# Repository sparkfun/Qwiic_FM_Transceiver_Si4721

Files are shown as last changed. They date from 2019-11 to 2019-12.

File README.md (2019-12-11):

# Qwiic FM Transceiver - Si4721

Qwiic FM Transceiver

[*Qwiic FM Transceiver - Si4721 (SPX-15853)*](https://www.sparkfun.com/products/15853)

You're probably already familiar with Silicon Labs' brilliant 47xx line of radio devices. We've been carrying their FM tuners for a long time and find them reliable and simple to operate. That said, we thought it would be nice if you could _transmit_ as well as _receive_, so we looked into it and we found this excellent FM Transceiver!

The Si4721 integrates the complete tuner and transmit functions from previous Si47xx devices into one chip for both FM broadcast reception and standards-compliant*, unlicensed FM broadcast stereo transmission. On top of stereo audio the Si4721 will also transmit and receive RDS/RBDS, allowing you to send and receive strings of text on the FM Band. This is the same technology that modern commercial stations use to broadcast things like call signs and song names but we think you could have fun using it to broadcast sensor data or other arbitrary text data.

In order to be compliant with most broadcast regulations, this transmitter is extremely low power and has a reliable range of maybe 10 to 20 meters. These types of transmitters are most often found in things like intercoms or car stereo audio input adapters. Within range, however, the audio signal is extremely clear. 

The Qwiic FM Transceiver board includes not only the Si4721 IC but also a 3.5mm audio jack for line level input, a 3.5mm audio jack providing headphone level output via the on-board TPA6111 headphone amp, and a two position poke-home connector for easy antenna connection. The I²C address is jumper configurable between 0x11 and 0x63, allowing for multiple radio boards on a single Qwiic bus.

*In many parts of the world, using extremely low-power transmitters in the FM band for non-commercial purposes requires no license but you should always check the local laws just in case! <b>You are responsible for complying with local RF transmission regulations.
  
  Repository Contents
-------------------
* **/Hardware** - Eagle design files (.brd, .sch)

Documentation
--------------
* **[Arduino Radio Library](https://cdn.sparkfun.com/assets/f/2/a/3/6/Radio.zip)** - This is an archived (.zip) fork of the [Radio](https://github.com/mathertel/Radio) library with added Si4721 support and example code. 

License Information
-------------------

This product is _**open source**_! 

Please review the LICENSE.md file for license information. 

If you have any questions or concerns on licensing, please contact technical support through the [SparkFun forum](https://forum.sparkfun.com/index.php).

Please use, reuse, and modify these files as you see fit. Please maintain attribution to SparkFun Electronics and release any derivative under the same license.

Distributed as-is; no warranty is given.

- Your friends at SparkFun.

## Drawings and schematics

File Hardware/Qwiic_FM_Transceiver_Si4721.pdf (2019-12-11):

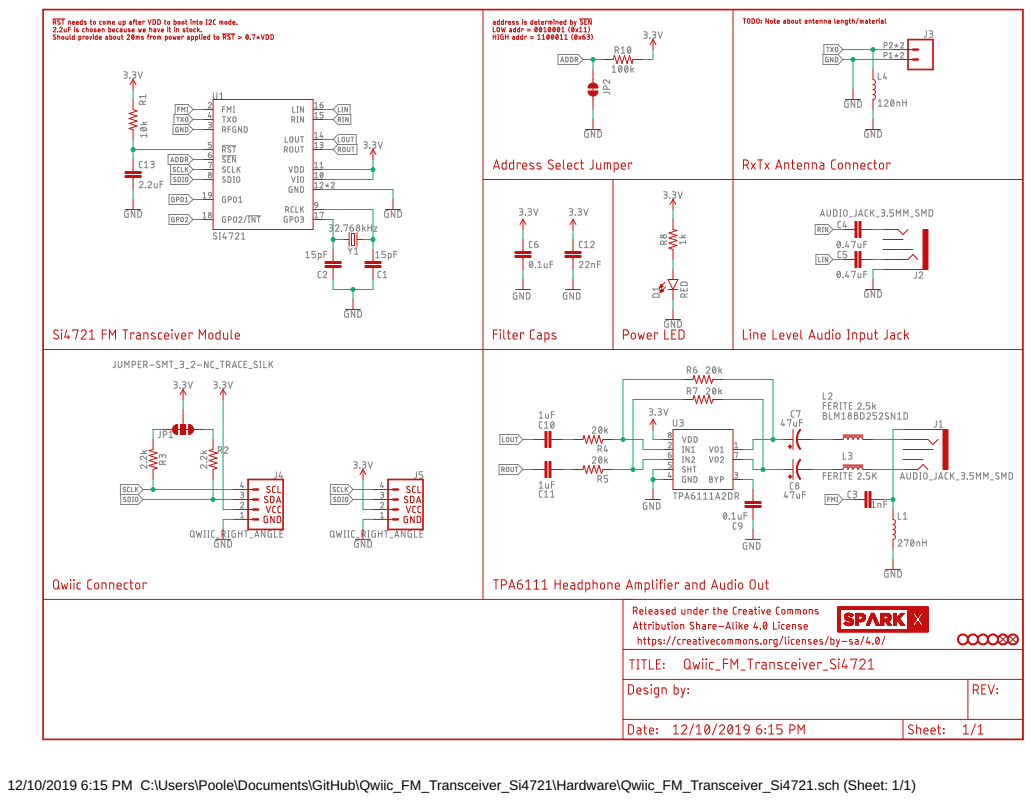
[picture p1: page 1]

12/10/2019 6:15 PM C:\Users\Poole\Documents\GitHub\Qwiic_FM_Transceiver_Si4721\Hardware\Qwiic_FM_Transceiver_Si4721.sch (Sheet: 1/1)

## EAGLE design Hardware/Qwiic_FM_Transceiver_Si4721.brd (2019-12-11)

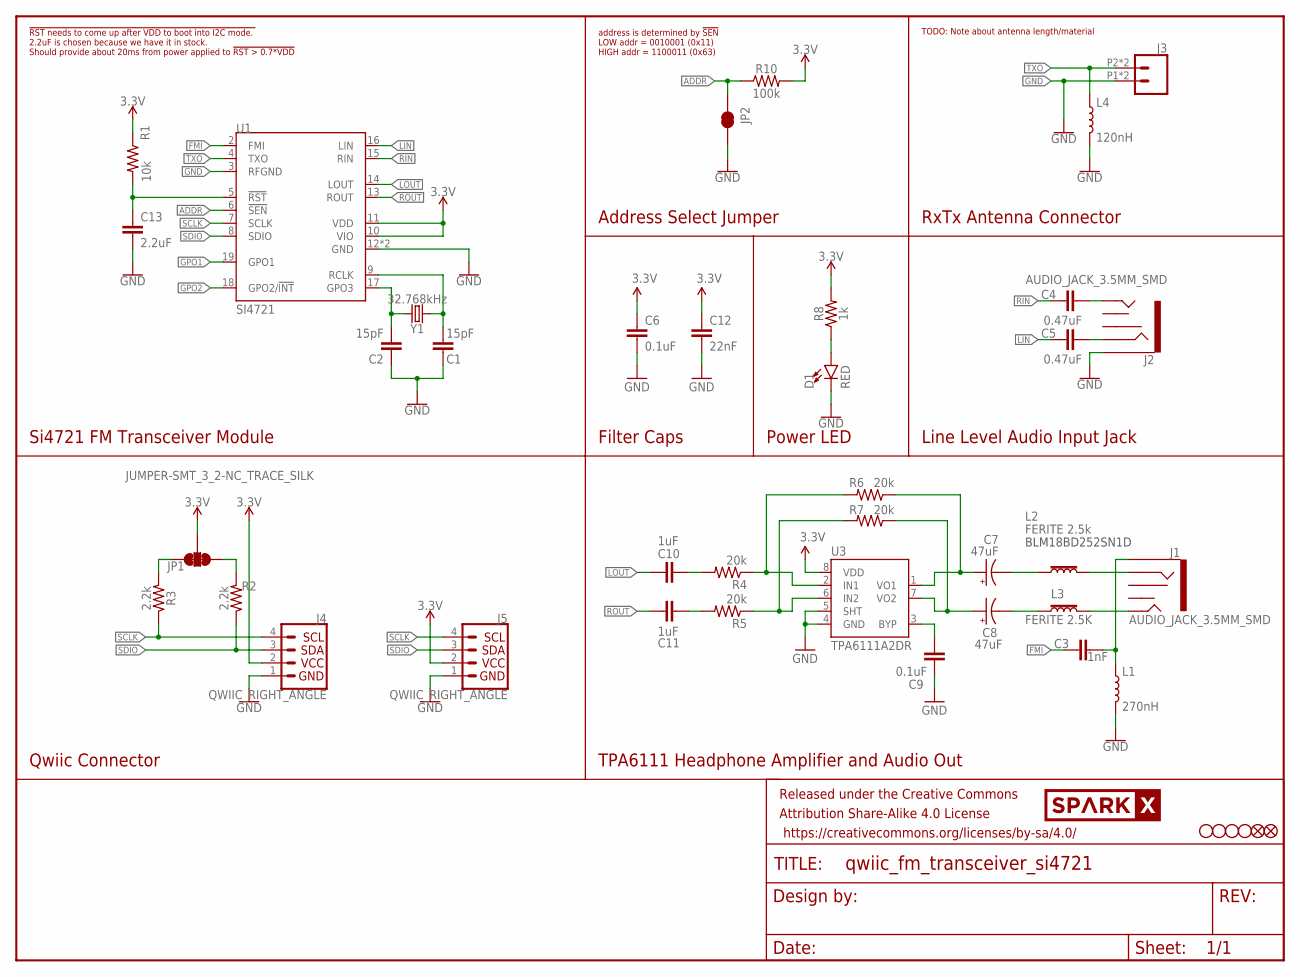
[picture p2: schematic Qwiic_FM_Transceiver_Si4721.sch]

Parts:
C1, C2: 15pF; 0603
C3: 1nF; 0603
C4, C5: 0.47uF; 0603
C6, C9: 0.1uF; 0603
C7, C8: 47uF; EIA3528
C10, C11: 1uF; 0603-CAP
C12: 22nF; 0603
C13: 2.2uF; 0603
D1: RED; LED-0603
FD1, FD2: FIDUCIAL0.2MM; FIDUCIAL-0.2MM
FRAME1: FRAME-LETTER; CREATIVE_COMMONS
H1, H2, H3, H4: STAND-OFF
J1, J2: AUDIO_JACK_3.5MM_SMD; AUDIO-JACK-3.5MM-SMD
J3: CONN_02SMALL_POKEHOME; 1X02_POKEHOME
J4, J5: QWIIC_RIGHT_ANGLE; JST04_1MM_RA
JP1: JUMPER-SMT_3_2-NC_TRACE_SILK; SMT-JUMPER_3_2-NC_TRACE_SILK
JP2: JUMPER-SMT_2_NC_TRACE_SILK; SMT-JUMPER_2_NC_TRACE_SILK
L1: 270nH; 0603
L2: FERITE 2.5k; 0603
L3: FERITE 2.5K; 0603
L4: 120nH; 0603
R1: 10k; 0603
R2, R3: 2.2k; 0603
R4, R5, R6, R7: 20k; 0603
R8: 1k; 0603
R10: 100k; 0603
U1: SI4721; QFN-20-3X3MM
U3: TPA6111A2DR; SO08
U$18: SPARKX-LOGO4; SPARKX-MEDIUM
Y1: 32.768kHz; CRYSTAL-SMD-3.2X1.5MM

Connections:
3.3V: C6.1, C12.1, J4.2, J5.2, JP1.2, R1.1, R8.2, R10.2, U1.10 (VIO), U1.11 (VDD), U3.8 (VDD)
ADDR: JP2.1, R10.1, U1.6 (!SEN)
FMI: C3.1, U1.2 (FMI)
GND: C1.1, C2.1, C6.2, C9.2, C12.2, C13.2, D1.C, J2.SLEEVE, J3.P1 (1), J3.P3 (1), J4.1, J5.1, JP2.2, L1.2, L4.2, U1.3 (RFGND), U1.12 (GND), U1.21 (GND), U3.4 (GND), U3.5 (SHT)
GPO1: U1.19 (GPO1)
GPO2: U1.18 (GPO2/!INT)
LIN: C5.1, U1.16 (LIN)
LOUT: C10.1, U1.14 (LOUT)
unnamed: C13.1, R1.2, U1.5 (!RST)
unnamed: C1.2, U1.9 (RCLK), Y1.P$1 (1)
unnamed: J1.RING, L2.2
unnamed: J1.TIP, L3.2
unnamed: C3.2, J1.SLEEVE, L1.1
unnamed: C4.2, J2.TIP
unnamed: C7.A (+), R6.1, U3.1 (VO1)
unnamed: C2.2, U1.17 (GPO3), Y1.P$2 (2)
unnamed: C8.A (+), R7.1, U3.7 (VO2)
unnamed: C9.1, U3.3 (BYP)
unnamed: R4.1, R6.2, U3.2 (IN1)
unnamed: R5.1, R7.2, U3.6 (IN2)
unnamed: C10.2, R4.2
unnamed: C11.2, R5.2
unnamed: C7.C (-), L2.1
unnamed: C8.C (-), L3.1
unnamed: C5.2, J2.RING
unnamed: JP1.3, R2.2
unnamed: JP1.1, R3.2
unnamed: D1.A, R8.1
RIN: C4.1, U1.15 (RIN)
ROUT: C11.1, U1.13 (ROUT)
SCLK: J4.4, J5.4, R3.1, U1.7 (SCLK)
SDIO: J4.3, J5.3, R2.1, U1.8 (SDIO)
TXO: J3.P2 (2), J3.P4 (2), L4.1, U1.4 (TXO)

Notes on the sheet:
BLM18BD252SN1D
Si4721 FM Transceiver Module
Address Select Jumper
Power LED
Line Level Audio Input Jack
RxTx Antenna Connector
Qwiic Connector
TPA6111 Headphone Amplifier and Audio Out
Filter Caps
address is determined by !SEN LOW addr = 0010001 (0x11) HIGH addr = 1100011 (0x63)
TODO: Note about antenna length/material
!RST needs to come up after VDD to boot into I2C mode. 2.2uF is chosen because we have it in stock. Should provide about 20ms from power applied to !RST > 0.7*VDD

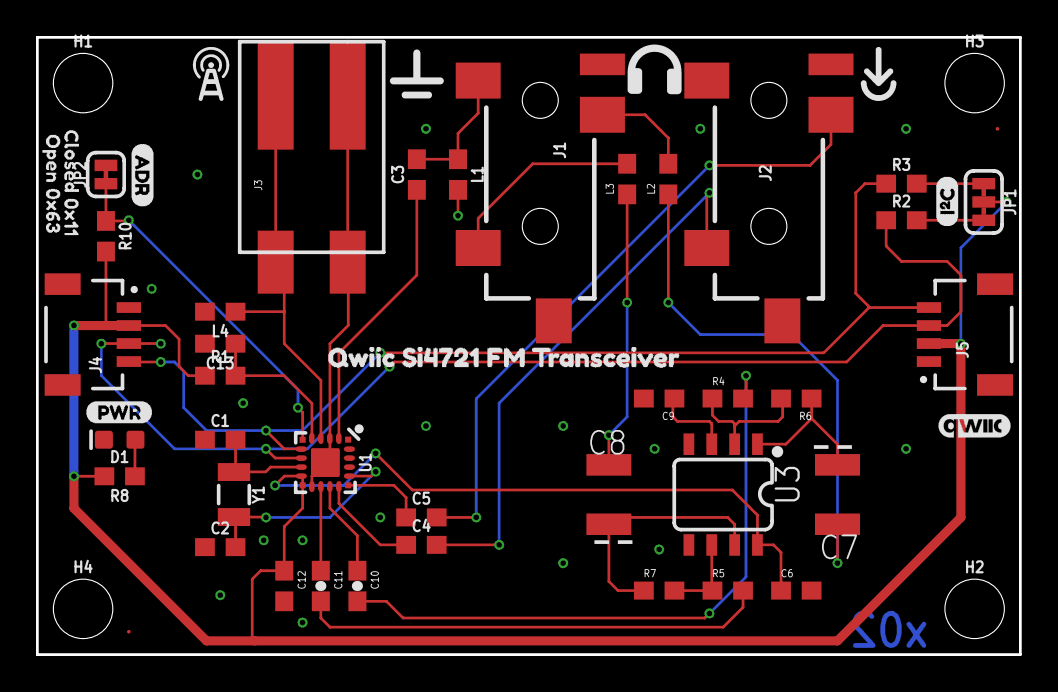
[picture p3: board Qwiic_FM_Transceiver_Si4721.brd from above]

Board: 2 copper layers, 54.6 x 34.3 mm, 62 parts (7 on the bottom side), 31 nets.

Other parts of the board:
U$1, U$2: QWIIC_SI4721_FM_TRANSCEIVER0
U$3: QWIIC_4MM
U$4: ANTENNA1
U$5: PWR-()-03
U$6: OSHW-LOGO-S
U$7: GND0
U$8: LINE_IN2
U$9: PHONES_OUT3
U$10: PHONES#PNG
U$11: IN#PNG
U$12: GND#PNG
U$13: ANTENNA#PNG
U$14: I_SUPER2_C-()-03
U$15: CLOSED_0X110
U$16: ADR-()-03
U$17: OPEN_0X631

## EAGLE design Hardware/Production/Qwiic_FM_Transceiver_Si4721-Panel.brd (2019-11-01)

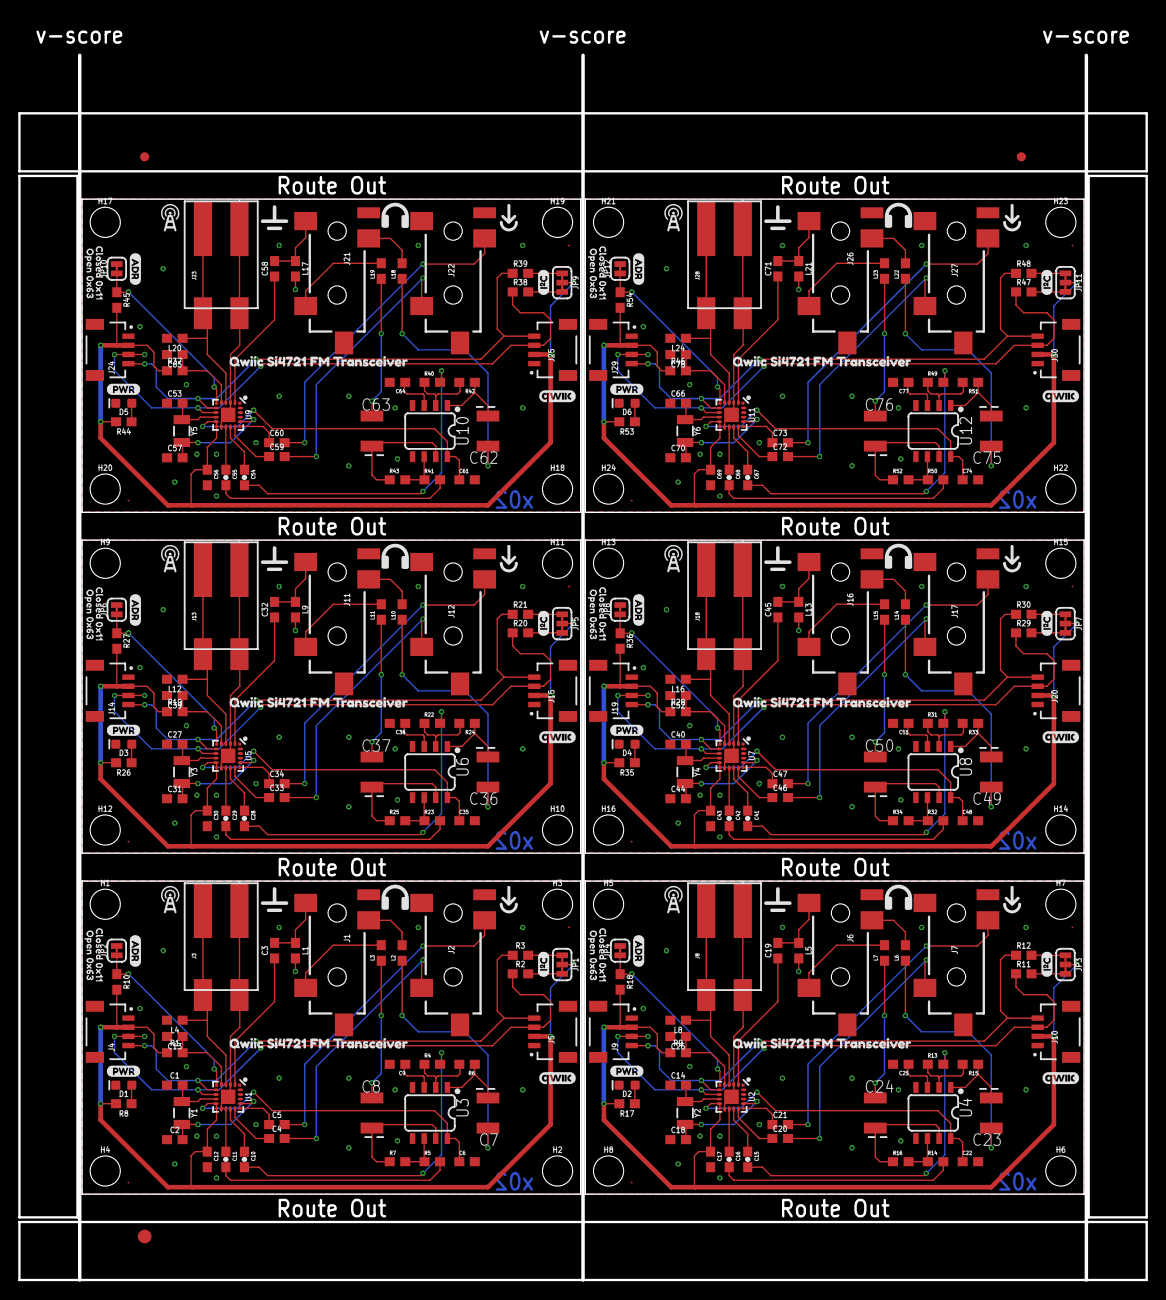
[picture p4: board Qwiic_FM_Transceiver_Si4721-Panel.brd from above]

Board: 2 copper layers, 123.4 x 134.1 mm, 369 parts (42 on the bottom side), 186 nets.

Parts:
C1, C2, C14, C18, C27, C31, C40, C44, C53, C57, C66, C70: 15pF; 0603
C3, C19, C32, C45, C58, C71: 1nF; 0603
C4, C5, C20, C21, C33, C34, C46, C47, C59, C60, C72, C73: 0.47uF; 0603
C6, C9, C22, C25, C35, C38, C48, C51, C61, C64, C74, C77: 0.1uF; 0603
C7, C8, C23, C24, C36, C37, C49, C50, C62, C63, C75, C76: 47uF; EIA3528
C10, C11, C15, C16, C28, C29, C41, C42, C54, C55, C67, C68: 1uF; 0603-CAP
C12, C17, C30, C43, C56, C69: 22nF; 0603
C13, C26, C39, C52, C65, C78: 2.2uF; 0603
D1, D2, D3, D4, D5, D6: RED; LED-0603
E$1, E$2: FIDUCIAL-1X2
E$3: FIDUCIAL-1.5X3
FD1, FD2, FD3, FD4, FD5, FD6, FD7, FD8, FD9, FD10, FD11, FD12: FIDUCIAL0.2MM; FIDUCIAL-0.2MM
H1, H2, H3, H4, H5, H6, H7, H8, H9, H10, H11, H12, H13, H14, H15, H16, H17, H18, H19, H20, H21, H22, H23, H24: STAND-OFF
J1, J2, J6, J7, J11, J12, J16, J17, J21, J22, J26, J27: AUDIO_JACK_3.5MM_SMD; AUDIO-JACK-3.5MM-SMD
J3, J8, J13, J18, J23, J28: 1X02_POKEHOME
J4, J5, J9, J10, J14, J15, J19, J20, J24, J25, J29, J30: QWIIC_RIGHT_ANGLE; JST04_1MM_RA
JP1, JP3, JP5, JP7, JP9, JP11: JUMPER-SMT_3_2-NC_TRACE_SILK; SMT-JUMPER_3_2-NC_TRACE_SILK
JP2, JP4, JP6, JP8, JP10, JP12: SMT-JUMPER_2_NC_TRACE_SILK
L1, L5, L9, L13, L17, L21: 270nH; 0603
L2, L6, L10, L14, L18, L22: FERITE 2.5k; 0603
L3, L7, L11, L15, L19, L23: FERITE 2.5K; 0603
L4, L8, L12, L16, L20, L24: 120nH; 0603
R1, R9, R19, R28, R37, R46: 10k; 0603
R2, R3, R11, R12, R20, R21, R29, R30, R38, R39, R47, R48: 2.2k; 0603
R4, R5, R6, R7, R13, R14, R15, R16, R22, R23, R24, R25, R31, R32, R33, R34, R40, R41, R42, R43, R49, R50, R51, R52: 20k; 0603
R8, R17, R26, R35, R44, R53: 1k; 0603
R10, R18, R27, R36, R45, R54: 100k; 0603
U1, U2, U5, U7, U9, U11: SI4721; QFN-20-3X3MM
U3, U4, U6, U8, U10, U12: TPA6111A2DR; SO08
U$1, U$2, U$19, U$31, U$37, U$49, U$55, U$67, U$73, U$85, U$91, U$103: QWIIC_SI4721_FM_TRANSCEIVER0
U$3, U$20, U$38, U$56, U$74, U$92: QWIIC_4MM
U$4, U$22, U$40, U$58, U$76, U$94: ANTENNA1
U$5, U$32, U$50, U$68, U$86, U$104: PWR-()-03
U$6, U$21, U$39, U$57, U$75, U$93: OSHW-LOGO-S
U$7, U$23, U$41, U$59, U$77, U$95: GND0
U$8, U$24, U$42, U$60, U$78, U$96: LINE_IN2
U$9, U$25, U$43, U$61, U$79, U$97: PHONES_OUT3
U$10, U$26, U$44, U$62, U$80, U$98: PHONES#PNG
U$11, U$27, U$45, U$63, U$81, U$99: IN#PNG
U$12, U$28, U$46, U$64, U$82, U$100: GND#PNG
U$13, U$29, U$47, U$65, U$83, U$101: ANTENNA#PNG
U$14, U$33, U$51, U$69, U$87, U$105: I_SUPER2_C-()-03
U$15, U$35, U$53, U$71, U$89, U$107: CLOSED_0X110
U$16, U$34, U$52, U$70, U$88, U$106: ADR-()-03
U$17, U$36, U$54, U$72, U$90, U$108: OPEN_0X631
U$18, U$30, U$48, U$66, U$84, U$102: SPARKX-LOGO4; SPARKX-MEDIUM
Y1, Y2, Y3, Y4, Y5, Y6: 32.768kHz; CRYSTAL-SMD-3.2X1.5MM

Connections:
3.3V: C6.1, C12.1, J4.2, J5.2, JP1.2, R1.1, R8.2, R10.2, U1.10, U1.11, U3.8
3.3V1: C17.1, C22.1, J9.2, J10.2, JP3.2, R9.1, R17.2, R18.2, U2.10, U2.11, U4.8
3.3V2: C30.1, C35.1, J14.2, J15.2, JP5.2, R19.1, R26.2, R27.2, U5.10, U5.11, U6.8
3.3V3: C43.1, C48.1, J19.2, J20.2, JP7.2, R28.1, R35.2, R36.2, U7.10, U7.11, U8.8
3.3V4: C56.1, C61.1, J24.2, J25.2, JP9.2, R37.1, R44.2, R45.2, U9.10, U9.11, U10.8
3.3V5: C69.1, C74.1, J29.2, J30.2, JP11.2, R46.1, R53.2, R54.2, U11.10, U11.11, U12.8
ADDR: JP2.1, R10.1, U1.6
ADDR1: JP4.1, R18.1, U2.6
ADDR2: JP6.1, R27.1, U5.6
ADDR3: JP8.1, R36.1, U7.6
ADDR4: JP10.1, R45.1, U9.6
ADDR5: JP12.1, R54.1, U11.6
FMI: C3.1, U1.2
FMI1: C19.1, U2.2
FMI2: C32.1, U5.2
FMI3: C45.1, U7.2
FMI4: C58.1, U9.2
FMI5: C71.1, U11.2
GND: C1.1, C2.1, C6.2, C9.2, C12.2, C13.2, D1.C, J2.SLEEVE, J3.P1, J3.P3, J4.1, J5.1, JP2.2, L1.2, L4.2, U1.3, U1.12, U1.21, U3.4, U3.5
GND1: C14.1, C17.2, C18.1, C22.2, C25.2, C26.2, D2.C, J7.SLEEVE, J8.P1, J8.P3, J9.1, J10.1, JP4.2, L5.2, L8.2, U2.3, U2.12, U2.21, U4.4, U4.5
GND2: C27.1, C30.2, C31.1, C35.2, C38.2, C39.2, D3.C, J12.SLEEVE, J13.P1, J13.P3, J14.1, J15.1, JP6.2, L9.2, L12.2, U5.3, U5.12, U5.21, U6.4, U6.5
GND3: C40.1, C43.2, C44.1, C48.2, C51.2, C52.2, D4.C, J17.SLEEVE, J18.P1, J18.P3, J19.1, J20.1, JP8.2, L13.2, L16.2, U7.3, U7.12, U7.21, U8.4, U8.5
GND4: C53.1, C56.2, C57.1, C61.2, C64.2, C65.2, D5.C, J22.SLEEVE, J23.P1, J23.P3, J24.1, J25.1, JP10.2, L17.2, L20.2, U9.3, U9.12, U9.21, U10.4, U10.5
GND5: C66.1, C69.2, C70.1, C74.2, C77.2, C78.2, D6.C, J27.SLEEVE, J28.P1, J28.P3, J29.1, J30.1, JP12.2, L21.2, L24.2, U11.3, U11.12, U11.21, U12.4, U12.5
LIN: C5.1, U1.16
LIN1: C21.1, U2.16
LIN2: C34.1, U5.16
LIN3: C47.1, U7.16
LIN4: C60.1, U9.16
LIN5: C73.1, U11.16
LOUT: C10.1, U1.14
LOUT1: C15.1, U2.14
LOUT2: C28.1, U5.14
LOUT3: C41.1, U7.14
LOUT4: C54.1, U9.14
LOUT5: C67.1, U11.14
unnamed: C13.1, R1.2, U1.5
unnamed: C1.2, U1.9, Y1.P$1
unnamed: J1.RING, L2.2
unnamed: J1.TIP, L3.2
unnamed: C3.2, J1.SLEEVE, L1.1
unnamed: C4.2, J2.TIP
unnamed: C7.A, R6.1, U3.1
unnamed: C2.2, U1.17, Y1.P$2
unnamed: C8.A, R7.1, U3.7
unnamed: C9.1, U3.3
unnamed: R4.1, R6.2, U3.2
unnamed: R5.1, R7.2, U3.6
unnamed: C10.2, R4.2
unnamed: C11.2, R5.2
unnamed: C7.C, L2.1
unnamed: C8.C, L3.1
unnamed: C5.2, J2.RING
unnamed: JP1.3, R2.2
unnamed: JP1.1, R3.2
unnamed: D1.A, R8.1
unnamed: C14.2, U2.9, Y2.P$1
unnamed: C18.2, U2.17, Y2.P$2
unnamed: C26.1, R9.2, U2.5
unnamed: C19.2, J6.SLEEVE, L5.1
unnamed: C23.A, R15.1, U4.1
unnamed: C24.A, R16.1, U4.7
unnamed: C25.1, U4.3
unnamed: R13.1, R15.2, U4.2
unnamed: R14.1, R16.2, U4.6
unnamed: C15.2, R13.2
unnamed: C16.2, R14.2
unnamed: C23.C, L6.1
unnamed: C24.C, L7.1
unnamed: J6.RING, L6.2
unnamed: J6.TIP, L7.2
unnamed: C20.2, J7.TIP
unnamed: C21.2, J7.RING
unnamed: JP3.3, R11.2
unnamed: JP3.1, R12.2
unnamed: D2.A, R17.1
unnamed: C27.2, U5.9, Y3.P$1
unnamed: C31.2, U5.17, Y3.P$2
unnamed: C39.1, R19.2, U5.5
unnamed: C32.2, J11.SLEEVE, L9.1
unnamed: C36.A, R24.1, U6.1
unnamed: C37.A, R25.1, U6.7
unnamed: C38.1, U6.3
unnamed: R22.1, R24.2, U6.2
unnamed: R23.1, R25.2, U6.6
unnamed: C28.2, R22.2
unnamed: C29.2, R23.2
unnamed: C36.C, L10.1
unnamed: C37.C, L11.1
unnamed: J11.RING, L10.2
unnamed: J11.TIP, L11.2
unnamed: C33.2, J12.TIP
unnamed: C34.2, J12.RING
unnamed: JP5.3, R20.2
unnamed: JP5.1, R21.2
unnamed: D3.A, R26.1
unnamed: C40.2, U7.9, Y4.P$1
unnamed: C44.2, U7.17, Y4.P$2
unnamed: C52.1, R28.2, U7.5
unnamed: C45.2, J16.SLEEVE, L13.1
unnamed: C49.A, R33.1, U8.1
unnamed: C50.A, R34.1, U8.7
unnamed: C51.1, U8.3
unnamed: R31.1, R33.2, U8.2
unnamed: R32.1, R34.2, U8.6
unnamed: C41.2, R31.2
unnamed: C42.2, R32.2
unnamed: C49.C, L14.1
unnamed: C50.C, L15.1
unnamed: J16.RING, L14.2
unnamed: J16.TIP, L15.2
unnamed: C46.2, J17.TIP
unnamed: C47.2, J17.RING
unnamed: JP7.3, R29.2
unnamed: JP7.1, R30.2
unnamed: D4.A, R35.1
unnamed: C53.2, U9.9, Y5.P$1
unnamed: C57.2, U9.17, Y5.P$2
unnamed: C65.1, R37.2, U9.5
unnamed: C58.2, J21.SLEEVE, L17.1
unnamed: C62.A, R42.1, U10.1
unnamed: C63.A, R43.1, U10.7
unnamed: C64.1, U10.3
unnamed: R40.1, R42.2, U10.2
unnamed: R41.1, R43.2, U10.6
unnamed: C54.2, R40.2
unnamed: C55.2, R41.2
unnamed: C62.C, L18.1
unnamed: C63.C, L19.1
unnamed: J21.RING, L18.2
unnamed: J21.TIP, L19.2
unnamed: C59.2, J22.TIP
unnamed: C60.2, J22.RING
unnamed: JP9.3, R38.2
unnamed: JP9.1, R39.2
unnamed: D5.A, R44.1
unnamed: C66.2, U11.9, Y6.P$1
unnamed: C70.2, U11.17, Y6.P$2
unnamed: C78.1, R46.2, U11.5
unnamed: C71.2, J26.SLEEVE, L21.1
unnamed: C75.A, R51.1, U12.1
unnamed: C76.A, R52.1, U12.7
unnamed: C77.1, U12.3
unnamed: R49.1, R51.2, U12.2
unnamed: R50.1, R52.2, U12.6
unnamed: C67.2, R49.2
unnamed: C68.2, R50.2
unnamed: C75.C, L22.1
unnamed: C76.C, L23.1
unnamed: J26.RING, L22.2
unnamed: J26.TIP, L23.2
unnamed: C72.2, J27.TIP
unnamed: C73.2, J27.RING
unnamed: JP11.3, R47.2
unnamed: JP11.1, R48.2
unnamed: D6.A, R53.1
RIN: C4.1, U1.15
RIN1: C20.1, U2.15
RIN2: C33.1, U5.15
RIN3: C46.1, U7.15
RIN4: C59.1, U9.15
RIN5: C72.1, U11.15
ROUT: C11.1, U1.13
ROUT1: C16.1, U2.13
ROUT2: C29.1, U5.13
ROUT3: C42.1, U7.13
ROUT4: C55.1, U9.13
ROUT5: C68.1, U11.13
SCLK: J4.4, J5.4, R3.1, U1.7
SCLK1: J9.4, J10.4, R12.1, U2.7
SCLK2: J14.4, J15.4, R21.1, U5.7
SCLK3: J19.4, J20.4, R30.1, U7.7
SCLK4: J24.4, J25.4, R39.1, U9.7
SCLK5: J29.4, J30.4, R48.1, U11.7
SDIO: J4.3, J5.3, R2.1, U1.8
SDIO1: J9.3, J10.3, R11.1, U2.8
SDIO2: J14.3, J15.3, R20.1, U5.8
SDIO3: J19.3, J20.3, R29.1, U7.8
SDIO4: J24.3, J25.3, R38.1, U9.8
SDIO5: J29.3, J30.3, R47.1, U11.8
TXO: J3.P2, J3.P4, L4.1, U1.4
TXO1: J8.P2, J8.P4, L8.1, U2.4
TXO2: J13.P2, J13.P4, L12.1, U5.4
TXO3: J18.P2, J18.P4, L16.1, U7.4
TXO4: J23.P2, J23.P4, L20.1, U9.4
TXO5: J28.P2, J28.P4, L24.1, U11.4

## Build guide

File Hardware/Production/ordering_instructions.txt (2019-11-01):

panel size, 124x128mm
PCB thickness, 1.6mm
number of layers, 2
soldermask color, Black
silkscreen color, White
oz copper, 1oz
finish, HASL lead free
stencils, top
pcs per panel, 6
min trace width, 0.152400mm / 0.006000in
min drill size, 0.304800mm / 0.012000in

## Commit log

2019-09-26 Finished Schematic
    [Qwiic_FM_Transceiver_Si4721.brd, Qwiic_FM_Transceiver_Si4721.sch]
2019-09-27 x01
    x01
    [Qwiic_FM_Transceiver_Si4721.sch]
2019-09-27 x01 protos ordered
    [Qwiic_FM_Transceiver_Si4721-Panel.GBL, Qwiic_FM_Transceiver_Si4721-Panel.GBO, Qwiic_FM_Transceiver_Si4721-Panel.GBS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]
2019-11-01 x02 hardware order
    [Qwiic_FM_Transceiver_Si4721-Panel.GBL, Qwiic_FM_Transceiver_Si4721-Panel.GBO, Qwiic_FM_Transceiver_Si4721-Panel.GBS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]
2019-12-11 Clean-up
    Deleting unneccessary files and rearranging to make the repo presentable
    [Qwiic_FM_Transceiver_Si4721.GBL, Qwiic_FM_Transceiver_Si4721.GBO, Qwiic_FM_Transceiver_Si4721.GBS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]

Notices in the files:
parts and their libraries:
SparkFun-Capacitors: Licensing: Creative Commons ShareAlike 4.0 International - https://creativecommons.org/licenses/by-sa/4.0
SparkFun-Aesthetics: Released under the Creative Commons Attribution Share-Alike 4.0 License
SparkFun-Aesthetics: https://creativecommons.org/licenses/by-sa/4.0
